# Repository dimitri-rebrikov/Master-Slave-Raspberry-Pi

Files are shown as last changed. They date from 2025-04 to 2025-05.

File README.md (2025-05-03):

# Master-Slave-Raspberry-Pi
The project enables the Raspberry Pi to be a slave of another device.
If another device is turned on the Pi also turns on.
If another device turns off the Pi shutdowns and turns off.

# Circuit and board

Circuit

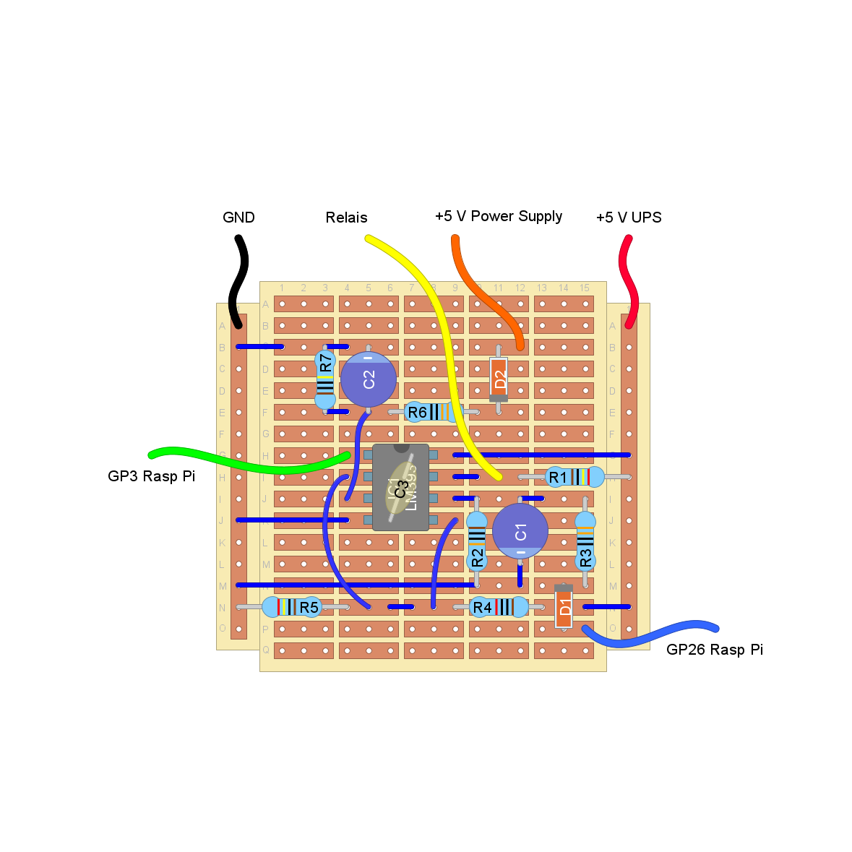
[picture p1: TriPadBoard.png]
Circuit board


# Implementation description
The functionality is build upon the Pi configuration possibility to:
- initiate the shutdown from the low signal on the GPIO 03 and 
- signal the finished shutdown with the hight signal on the GPIO 26.

For this the following parameters needs to be added to the `/boot/config.txt`
```
# enable shutdown on gpio 3 down
dtoverlay=gpio-shutdown

# enables high on gpio 26 after the system shutdown
dtoverlay=gpio-poweroff
```

## Circuit elements purpose

**UPS Module** continues to provide power if the main power supply is turned off

**Relays module 1** prevents the batteries drain if the device is unused for the long period of time

**Relays module 2** switches on/off the Raspberry Pi power supply

**R1** switches both relays on after the main power supply is turned on and the UPS starts to provide the power. Remark: the UPS provides the output power also without connected batteries in case the main power supply is on.
 
**IC1** inverts the high signal from GPIO 26 to low signal and turns off the both relays. It also implements the flip for the delay circuit R2, C1

**IC2** does not invert the signal but is necessary for the delay circuit to implement fast flip after the R7 drains the voltage on the C2 below the reference voltage of 1 V

**R2, C1** implement delay of ~ 2 sec before the Raspberry Pi is powered again in case the power was not interrupted but rather the shutdown was initiated over the command line.

**R7, C2** implement delay of ~ 40 sec between the main power los and the shutdown signal to the Raspberry Pi. This long period of time is necessary for the case the power supply is turned off immediately after being turned on, so the shutdown signal will be issued after the Pi's OS finished initialization and is able to react to the shutdown signal.

**R3, R6** are for current limiting

**D1, D2** prevent the backflow

**R4, R5** provide reference 1 V to the IC2, IC1 

**C3** is connected directly between "+" and "-" of the IC power pins as suggested by the reference implementation.

## Concrete implementation
My aim to implement this project was to embed the Raspberry Pi into my 3D Printer to use it with the [Octoprint software](https://octoprint.org/).
On the pictures below you can see the result:
- the electronic parts of the projects are mounted on a 3d printed base
- the base is mounted (with double side adhesive pads, plus cable ties) in the free space of the electronic compartment of the 3d printer (Creality CR-5 Pro)

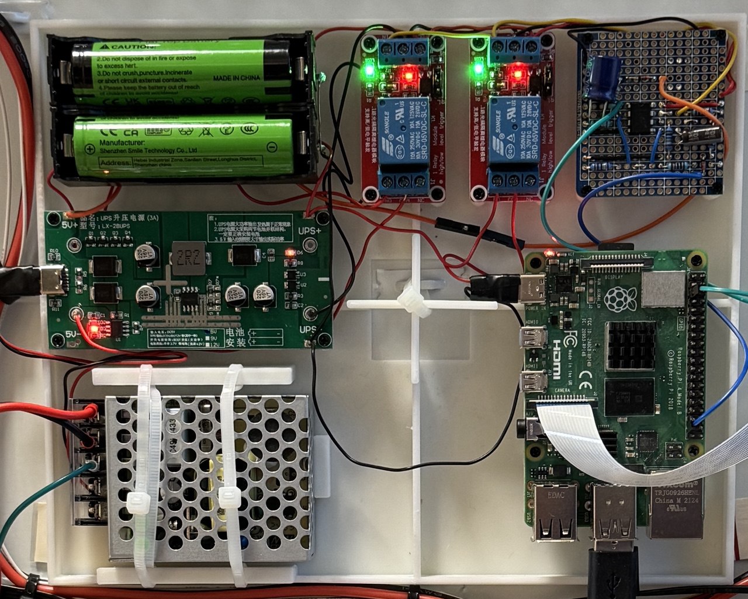
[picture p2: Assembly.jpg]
Assembly view

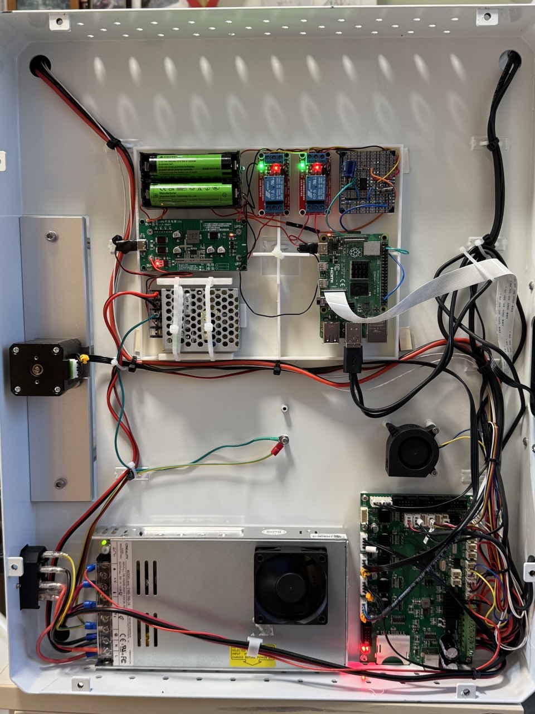
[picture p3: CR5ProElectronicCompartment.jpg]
Assembly inside of the CR-5 Pro electronic comparment


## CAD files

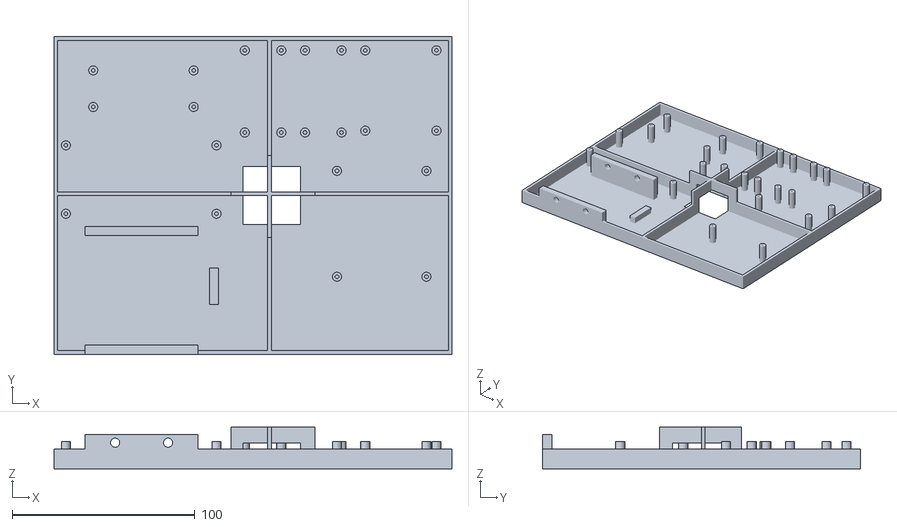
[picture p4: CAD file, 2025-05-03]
Base.stl
218.0 x 174.0 x 22.8

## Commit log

2025-03-07 Created first circuit sketch
2025-03-08 refactoring to turn of the complete circuit from the relais
2025-03-09 completely refactored schematics
2025-03-11 refacored poweroff delay
2025-03-13 refactored the poweroff delay
2025-03-13 added diodes type
2025-04-04 Refactored the circuit. Put relais between the battery and the UPS to prevent battery drain.
2025-04-06 Designed new board according to the changes circuit.
2025-04-12 Updated cicuit and layout based on the assembly results
2025-04-12 added circuit description
2025-04-16 adjusted C2/R7 to remove interferences. The R7 as 1M resulted not enough drain of the static voltage from intefrerences. So the value was lowered by factor 10 to 100u and C2 was increased correspondi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
2025-05-03 increased the value of C2 from 100uf to 220uf to ensure that wven the power supply is turned off imediately ofter turn of the shutdown signal will be send after the full initialization of the raspber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
2025-05-03 added the description of the assembly
    [Base.stl]
